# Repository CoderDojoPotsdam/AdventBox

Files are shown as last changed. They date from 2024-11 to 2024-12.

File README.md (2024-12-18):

# AdventBox

Ein Projekt des [CoderDojo Potsdam](https://coderdojopotsdam.github.io/) zum gemeinsamen Basteln und Programmieren in der Adventszeit.

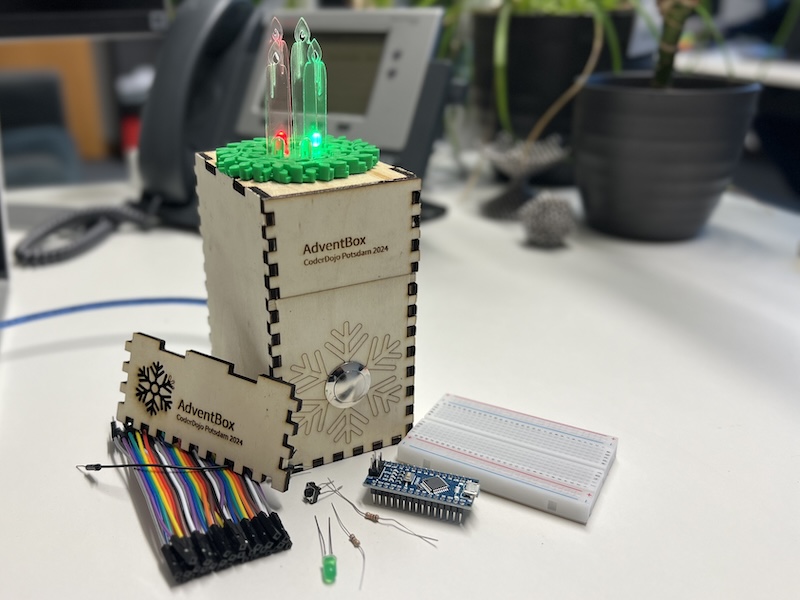
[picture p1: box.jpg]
Schaubild AdventBox


Die Box bietet eine Verkleidung für einen eigenen elektrischen Adventskranz.
Die vier Kerzen des Adventskranzes lassen sich mittels des Tasters nacheinander anschalten.

Auch wenn der Arduino vom Strom genommen wurde und wieder angesteckt wird, leuchtet die gleiche Anzahl Kerzen. So kannst du bequem die Wochen bis Weihnachten zählen.

## Materialien

- Arduino Nano oder ähnlicher Microcontroller
- 1 Breadboard
- 4 LEDs in der Farbe eurer Wahl
- 4 Widerstände 220 Ohm
- 1 Widerstand 100 kOhm
- 1 Taster
- diverse Jumperkabel oder Kabelbrücken

Außerdem zur Verschönerung:

- Holz für die Box
- Einen 3D-gedruckten Adventskranz
- Aus Acryl geschnittene Kerzen

## Anleitung

### 1. Ein Testlauf

1. Nimm ein Breadboard und setze den Arduino auf
2. Verbinde Pin D2 mit einem 220 Ohm Vorwiderstand und mit einer LED
3. Verbinde Pin D8 mit dem Taster und dahinter einem 100 kOhm Widerstand
4. Verbinde den Minus-Pol der LED und den 100 kOhm Widerstand mit GND am Arduino
5. Lade den Quellcode [AdventBoxBlink](AdventBoxBlink/) auf den Arduino

Wenn du alles richtig gemacht hast, kannst du abwechselnd die interne LED und externe LED blinken lassen.

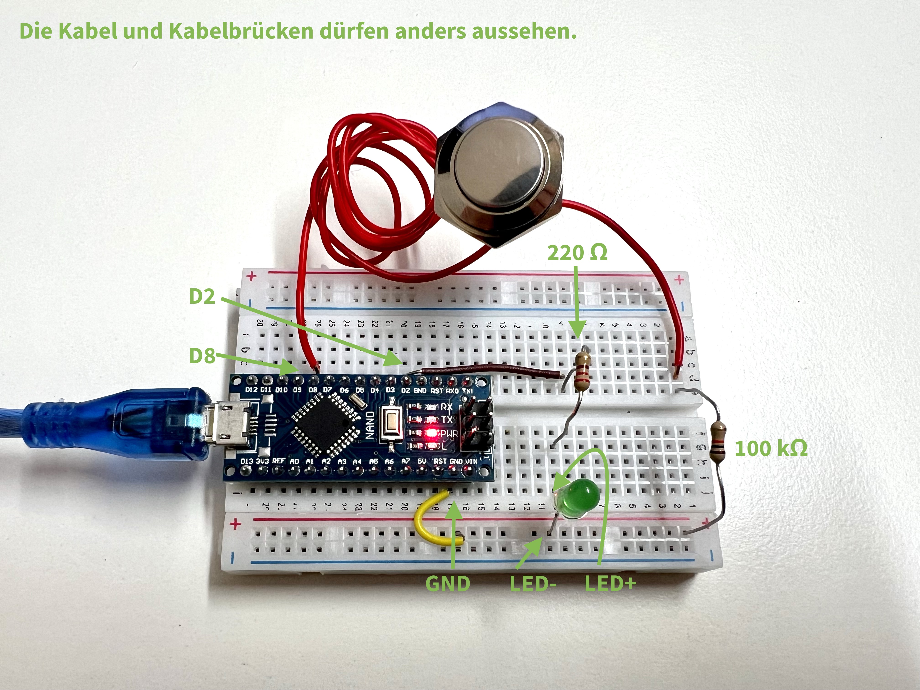
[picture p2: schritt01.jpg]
Schaubild Testlauf


Sollte die Schaltung nicht funktionieren, versuche den Taster direkt an den GND zu schließen, ohne den 110 kOhm Widerstand. Im Programm des Arduinos aktivieren wir einen zusätzlichen internen Widerstand (`INPUT_PULLUP`).

### 2. Die vollständige Schaltung

1. Füge drei weitere LEDs mit 220 Ohm Vorwiderständen hinzu.
2. Stelle sicher, dass die Plus-Pole der LEDs (langes Bein) an die Pins D2, D3, D7 und D10 angeschlossen sind.
3. Die Minuspole (kurzes Bein) kannst du auf den gemeinsamen Pin GND ziehen.
4. Lade den Quellcode [AdventBoxCode](AdventBoxCode/) auf den Arduino
  * Alternativ kannst du versuchen das Programm selbst zu schreiben. Beginn mit [AdventBoxEmpty](AdventBoxEmpty/). Die Anzahl der leuchtenden Kerzen kannst du im [EEPROM](https://docs.arduino.cc/learn/built-in-libraries/eeprom/) ablegen, damit sie auch bei getrennten Strom gespeichert werden.

Wenn du alles richtig gemacht hast, kannst du reihum die externen LEDs aufleuchten lassen.

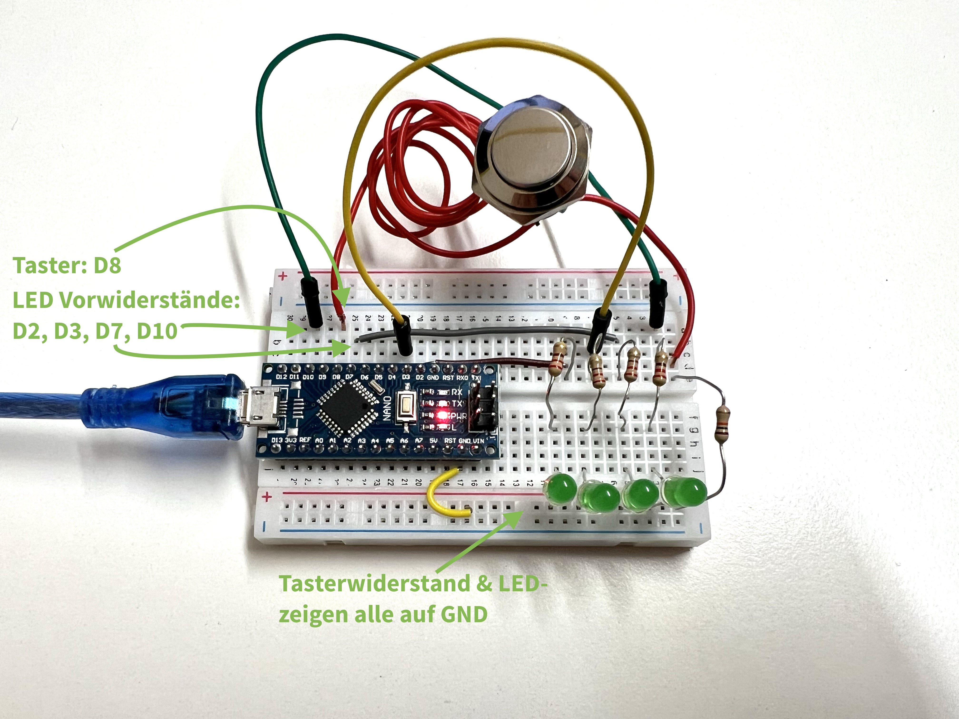
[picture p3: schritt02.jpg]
Schaubild Schaltung


### 3. Bau die Box

Fertige folgende Materialien an, oder frage die Mentor:innen danach:

1. Schneide mit dem Lasercutter die [Holzteile der Box](Lasercuttervorlagen/kasten_schnitt.02mm.svg).
2. Schneide mit dem Lasercutter zwei lange und zwei kurze [Kerzen aus Acryl](Lasercuttervorlagen/kerzen.svg).
3. Druck mit dem 3D-Drucker den [Kranz](kranz.stl) aus.
4. Bau die Box bis auf ein Seitenteil zusammen, sodass du bequem deine Schaltung in die Box setzen kannst.
5. Setz das Breadboard mit Arduino, Widerständen und Kabeln in die Box.
6. Verlängere die Anschlüsse der LEDs mit Jumperkabeln.
6. Fädle die Kabel zu den LEDs durch die großen Löcher im Adventskranz und steck die LEDs ein.
7. Schließ den Knopf an und teste deine Schaltung erneut.
8. Schließ die Kiste und setze die Kerzen in die kleinen Löcher auf deinen Kranz.
9. Optional: Du kannst den Kranz mit etwas Heißkleber befestigen.

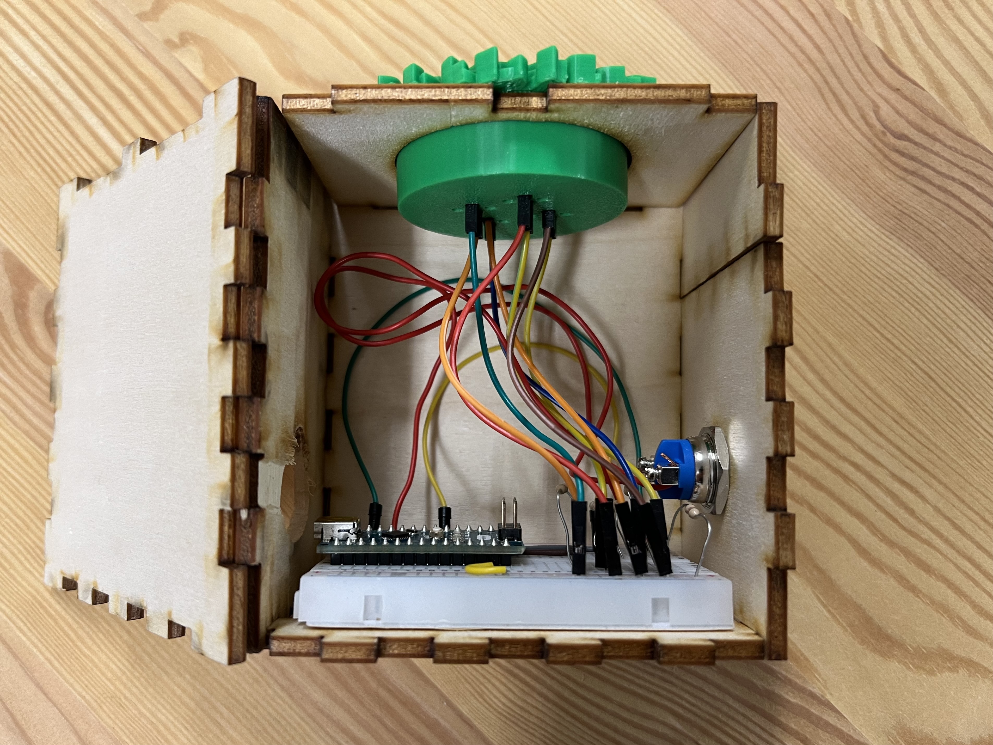
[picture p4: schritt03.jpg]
Schaubild offene Kiste


(Aus Fotogründen hingelegt. Baut sich einfacher aufrecht.)

**Frohen Advent!**

## Referenzen

* Schaltung basiert auf Vorlage von [Christian Grieger](https://elektro.turanis.de/html/prj404/index.html)
* Vorlage 3D-gedruckter Kranz: [Betsmo (Thingiverse)](https://www.thingiverse.com/thing:1937138), Lizenz CC-BY

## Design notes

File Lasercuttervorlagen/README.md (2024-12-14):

# Lassercuttervorlagen

Dieser Ordner enthält Dateien, die mit üblichen Lasercuttern geschnitten werden können.

## Die Box

Je nach Abbrennbreite des Lasers kannst du 0,0mm, 0,1mm oder 0,2mm Toleranz für de Box wählen.
Lade dafür die passende Datei herunter.

Alternativ kannst du auch sie ausdrucken, auf wirklich stabilen Karton kleben und mit einer Schere oder feinem Messer ausschneiden.

Der Entwurf ist für 4mm dickes Holz gedacht.

## Die Kerzen

Lasercutte dir zwei kurze und zwei Kerzen.
Der Entwurf ist für 2mm dickes Acryl gedacht.

Wenn du keinen Lasercutter hast, kannst du auch Frischhaltefolie zu einer Rolle drehen und senkrecht über die LEDs ziehen.

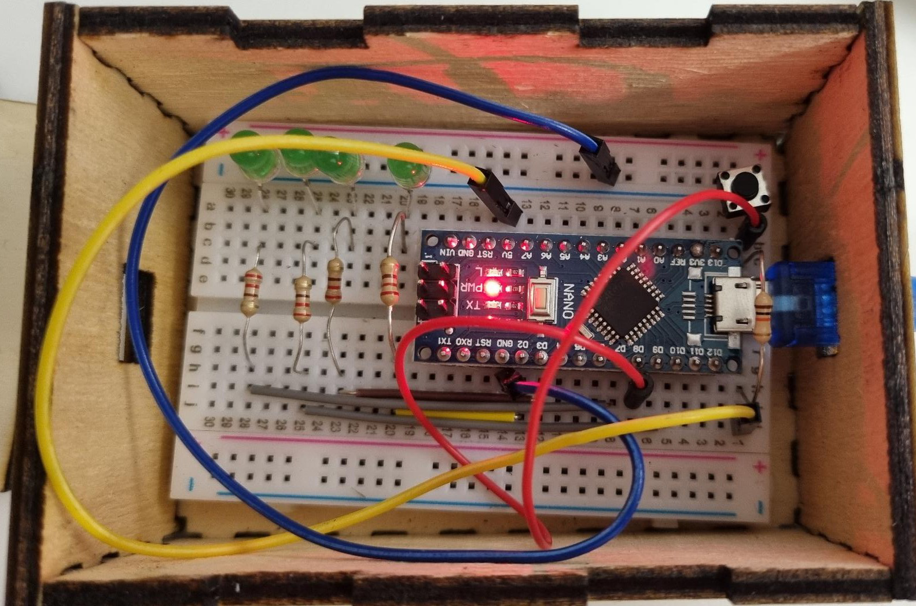
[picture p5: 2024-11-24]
Schaltung_Breadboard.jpeg

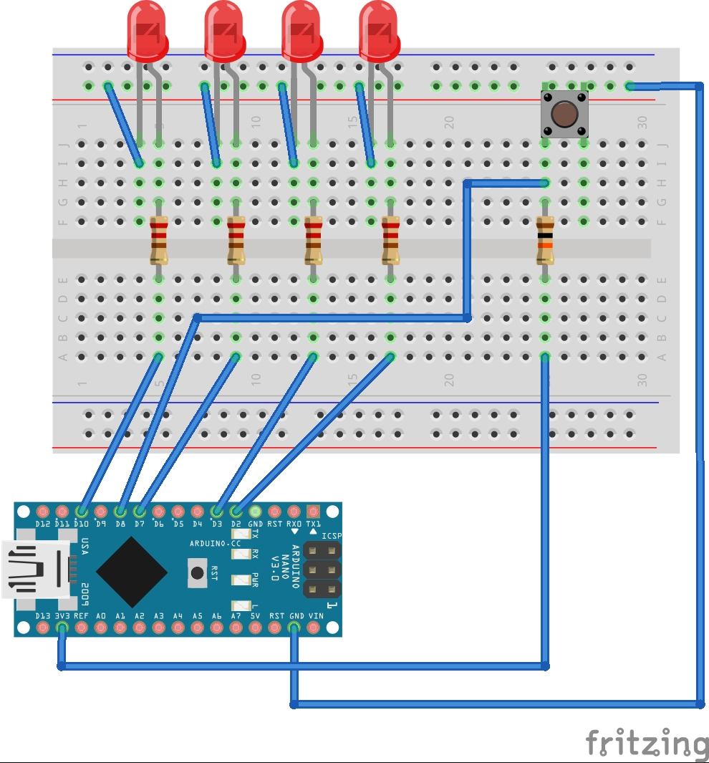
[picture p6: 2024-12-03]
Schaltplan_Breadboard_Arduino_Logisch.jpg

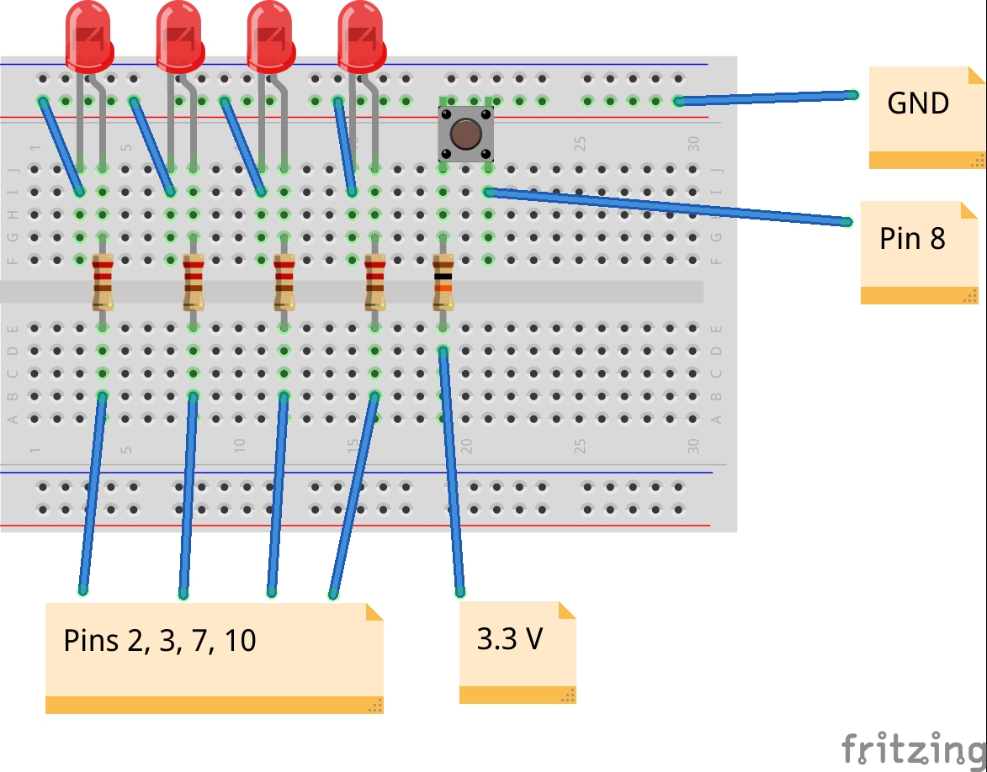
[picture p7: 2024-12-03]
Schaltplan_Breadboard_Logisch.jpg

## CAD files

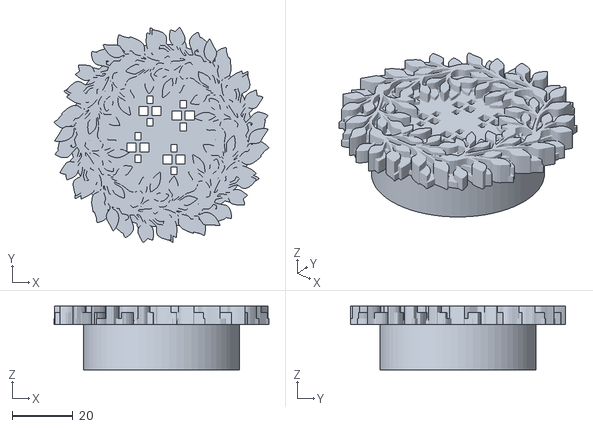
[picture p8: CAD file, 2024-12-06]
kranz.stl
71.0 x 71.0 x 21.0

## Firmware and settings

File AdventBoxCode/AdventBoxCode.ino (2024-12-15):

#include <EEPROM.h>

// Verzögerung in ms, sodass jeder Tastendruck nur einmal gezählt wird.
#define BUTTON_DELAY 250
// Verzägerung in ms, damit die LEDs nur langsam nacheinander aufleuchten.
#define LED_DELAY    0
#define lmillis() ((long)millis())

const byte numLeds = 4;
const byte eepromAddress = 0;
const byte buttonPin = 8;
const byte *ledPins[numLeds] = {2,3,7,10};
byte ledsLit = 0;
long lastButtonPress, lastLedToggle;

void setup()
{
  // Zur Fehlersuche den Kommentar "Serial.begin(9600)" auskommentieren und printf-Debugging über den seriellen Monitor durchführen
  // mit Serial.println(„mein Kommentar hier“)
  // Serial.begin(9600);

  // Ermittlung der Anzahl der LEDs, die vor dem Reset geleuchtet haben
  EEPROM.get(eepromAddress, ledsLit);
  ledsLit = max(0, min(4, ledsLit));
  
  // Pinmode des Buttons auf Eingabe festlegen und Referenzwert setzen
  pinMode(buttonPin, INPUT_PULLUP);
  digitalWrite(buttonPin, HIGH);

  // Pinmode der LED-Pins auf Ausgabe festlegen
  for (byte i = 0; i < numLeds; i++) {
      pinMode(ledPins[i], OUTPUT);
  }

  // Nummer der LED in ledsLit einschalten, wie vorher aus EEProm ausgelesen
  toggleLeds();

  lastButtonPress = lmillis() + BUTTON_DELAY;
  lastLedToggle = lmillis() + LED_DELAY;
}

void loop()
{
  // Prüfen, ob Button gedrückt wurde
  if (lmillis() - lastButtonPress >= BUTTON_DELAY && digitalRead(buttonPin) == LOW) {
    lastButtonPress = lmillis() + BUTTON_DELAY;
    ledsLit++;
    ledsLit %= (numLeds + 1);
    EEPROM.put(eepromAddress, ledsLit);
  }

  if (lmillis() - lastLedToggle >= LED_DELAY) {
    lastLedToggle = lmillis() + LED_DELAY;
    toggleLeds();
  }
}

void toggleLeds()
{
  // Zusatz A: Kannst du auch die LEDs in zufälliger Reihenfolge aufleuchten lassen?
  // Zusatz B: Kannst du auch die LEDs wie eine Kerze aufflackern lassen? Zum Beispiel mit der Bibliothek #include <SoftPWM.h>?
    for (byte i = 0; i < numLeds; i++) {
        if ((i + 1) <= ledsLit) {
            digitalWrite(ledPins[i], HIGH);
        } else {
            digitalWrite(ledPins[i], LOW);
        }
    }
}

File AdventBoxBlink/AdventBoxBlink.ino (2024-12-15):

#define BUTTON_DELAY 250
#define lmillis() ((long)millis())

const byte numLeds = 4;
const byte buttonPin = 8;
const byte ledPin = 2;

long lastButtonPress;

void toogleLEDs() {
  // Dieses "An" wird beim Einschalten in Setup ausgeschaltet
  // d.h. nach dem Start leuchtet die Interne LED und die externe ist aus
  static bool externalLedOn = true;
  externalLedOn = !externalLedOn;
  
  digitalWrite(ledPin,      externalLedOn ? HIGH : LOW );
  digitalWrite(LED_BUILTIN, externalLedOn ? LOW  : HIGH);
}

void setup() {
  pinMode(ledPin, OUTPUT);
  pinMode(LED_BUILTIN, OUTPUT);
  
  pinMode(buttonPin, INPUT_PULLUP);
  digitalWrite(buttonPin, HIGH);

  lastButtonPress = lmillis() + BUTTON_DELAY;
  toogleLEDs();
}


void loop() {
  if (lmillis() - lastButtonPress >= BUTTON_DELAY && digitalRead(buttonPin) == LOW) {
    lastButtonPress = lmillis() + BUTTON_DELAY;
    toogleLEDs();
  }
}

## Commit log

2024-11-24 Vorlagen Holzkasten und Kranz
    [kranz.stl]
2024-11-24 Add empty and complete files of Arduino files as difficult levels
2024-11-24 Add picture of circuit on breadboard
2024-12-03 Add logic circuit picture and a bit more description
2024-12-04 Kerzen und größere Box
2024-12-06 Höherer Kranz für besseren Halt
    [kranz.stl]
2024-12-10 Version des Kastens ohne Schnittbreite
2024-12-10 Version mit Schnittbreite 0,01mm
2024-12-12 Fix button
2024-12-14 Verschiebe Lasercutterdateien
2024-12-15 Bild der offenen Box
2024-12-18 Details zur LED Polarität
